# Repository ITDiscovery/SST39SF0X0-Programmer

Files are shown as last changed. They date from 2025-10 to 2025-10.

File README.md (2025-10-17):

# Arduino Mega Parallel Flash Programmer for SST39SF0X0

This project documents a reliable, breadboard-based programmer for SST39SF0X0 series parallel NOR flash chips (SST39SF010, SST39SF020, SST39SF040) using an Arduino Mega 2560. The system was developed to program custom multi-cartridges for the Tandy/Radio Shack Color Computer.

The programmer consists of an Arduino sketch that acts as a hardware interface and a Python script that streams a binary ROM file from a host computer (Mac, PC, or Linux) to the Arduino for programming.

---
## Hardware Required

* **Arduino Mega 2560 R3**: A 5V microcontroller with enough I/O pins to directly drive the flash chip.
* **SST39SF0X0 Series Chip**: e.g., SST39SF020 (256KB) or SST39SF040 (512KB).
* **Breadboard(s)**: Sufficient space for a 32-pin DIP chip and wiring.
* **Jumper Wires**: A good quality set is essential.
* **Two 0.1µF Ceramic Capacitors**: For power decoupling.

  Note: I tried initially to use a AVR128DA64, but timing and jitter created too many issues.

---
## Wiring Diagram

Proper wiring and power integrity are critical for success. Place one 0.1µF capacitor directly across the VCC and GND pins of the Arduino, and the other directly across the VCC and GND pins of the flash chip.

| Signal | SST39SF0X0 Pin | Mega 2560 Pin | Notes |
| :--- | :--- | :--- | :--- |
| **Address** | A0 - A15 | D22 - D37 | 16 contiguous address lines |
| | A16 - A18 | D38 - D40 | Upper 3 address lines |
| **Data** | D0 - D7 | D42 - D49 | Full 8-bit data bus |
| **Control** | #OE (Pin 24) | D50 | Output Enable |
| | #WE (Pin 31) | D51 | Write Enable |
| | #CE (Pin 11) | GND | Chip Enable (tied permanently LOW) |
| **Power** | VCC (Pin 32) | 5V | Connect to 5V rail |
| | GND (Pin 16) | GND | Connect to Ground rail |

---
## How to Use

### Step 1: Build Your Binary ROM File

Use the provided shell scripts to combine your individual 8K or 16K ROM files into a single binary image.

* **For an 8K Multi-Cart (SST39SF020):**
    * Edit the `build_cart.sh` script to list your 8K ROM files.
    * Run the script: `./build_cart.sh`
    * This creates `multicart.bin` (256KB).

* **For a 16K Multi-Cart (SST39SF040):**
    * Edit the `build_16k_cart.sh` script to list your 16K ROM files.
    * Run the script: `./build_16k_cart.sh`
    * This creates `multicart_16k.bin` (512KB).

### Step 2: Prepare the Arduino

1.  Connect your Arduino Mega to your computer.
2.  Open the `SST39SF0X0_Serial_Programmer.ino` sketch in the Arduino IDE.
3.  Upload the sketch to the Mega.
4.  Open the Serial Monitor and confirm it prints "READY".
5.  **Close the Serial Monitor.** This is critical, as the Python script needs exclusive access to the port.

### Step 3: Program the Chip

1.  Make sure Python 3 and the `pyserial` library are installed (`pip3 install pyserial`).
2.  Run the appropriate Python script from your terminal.

* **For the 8K Multi-Cart:**
    ```bash
    python3 upload8k.py
    ```

* **For the 16K Multi-Cart:**
    ```bash
    python3 upload16k.py
    ```
The script will auto-detect the serial port, erase the chip, and then write the binary file, showing you the progress.

---
## Project Files

* `SST39SF0X0_Serial_Programmer.ino`: The firmware for the Arduino Mega. This sketch turns the Arduino into a dedicated hardware programmer that listens for commands over the serial port.
* `upload8k.py`: A Python script for your host computer to program 256KB binary files (e.g., for an SST39SF020).
* `upload16k.py`: A Python script for your host computer to program 512KB binary files (e.g., for an SST39SF040).
* `build_cart.sh`: A shell script template to assemble multiple 8K ROMs into a single 256KB binary image.
* `build_16k_cart.sh`: A shell script template to assemble multiple 16K ROMs into a single 512KB binary image.

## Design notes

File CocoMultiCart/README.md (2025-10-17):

# Dragon64/CoCo Multi-Cartridge

This repository contains the complete hardware design files for a switchable multi-cartridge for the Dragon64/CoCo. The board supports various SST39SF0X0 series flash chips and uses an 8-position DIP switch for bank selection.

---
## Features

* **Chip Support**: Designed for SST39SF010 (128KB), SST39SF020 (256KB), and SST39SF040 (512KB) parallel NOR flash chips in a DIP-32 package.
* **Bank Switching**: An 8-position DIP switch allows for hardware-based bank selection.
* **8K/16K Mode**: A jumper allows for easy switching between 8K and 16K cartridge modes.
* **Custom Case**: Includes an STL file for a 3D-printable cartridge shell.

---
## Repository Contents

* `Gerber_CoCoMultiCart.zip`: Gerber files ready for submission to a PCB manufacturer (like JLCPCB, PCBWay, etc.).
* `CoCoCartridge1.stl`: Contains a matching `.stl` file for the 3D-printable cartridge case.
* `Schem_CoCoMultiCart.pdf`: A document containing the board schematic, layout, and other project details.

---
## How to Build Your Cartridge

### 1. Manufacture the PCB

Upload the `.zip` file from the `/Gerber/` directory to your preferred PCB fabrication service (shout out to JCLPCB).

### 2. Gather Components (Bill of Materials)

| Part | Quantity | Notes |
| :--- | :--- | :--- |
| Custom PCB | 1 | From the Gerber files. |
| SST39SF0X0 Chip | 1 | e.g., SST39SF020 for a 32-in-1 8K cart. |
| 32-pin DIP Socket | 1 | **Highly recommended** to avoid soldering the chip directly. |
| 8-Position DIP Switch | 1 | For bank selection. |
| 10kΩ Resistor Array | 1 | SIP-9 package, for switch pull-ups. |
| 0.1µF Capacitor | 1 | Power supply decoupling. |
| 3-pin Header | 2 | For the 8K/16K mode jumper, autostart jumper.  |
| Jumper Shunt | 2 | To place on the header. |

### 3. Assemble the Board

Solder all components onto the PCB according to the schematic in the PDF. Solder the DIP socket, not the flash chip itself.

### 4. Program the Flash Chip

The flash chip must be programmed **before** it is inserted into the socket on the cartridge.

Use the Arduino Mega Parallel Flash Programmer to build a multi-cart binary image and write it to the chip. Follow the instructions in that repository's README file.

### 5. Print the Case

Print the `.stl` file on your 3D printer to create a protective shell for your finished cartridge.

---
## Usage

1.  Insert the programmed chip into the socket on the cartridge board.
2.  Set the jumper to either **8K** or **16K** mode, depending on the multi-cart binary you created.
3.  Use the DIP switches to select the desired game bank. **Note:** The switches use inverted logic (ON = 0, OFF = 1) due to the pull-up resistors.
4.  Insert the cartridge into your Color Computer and power it on.

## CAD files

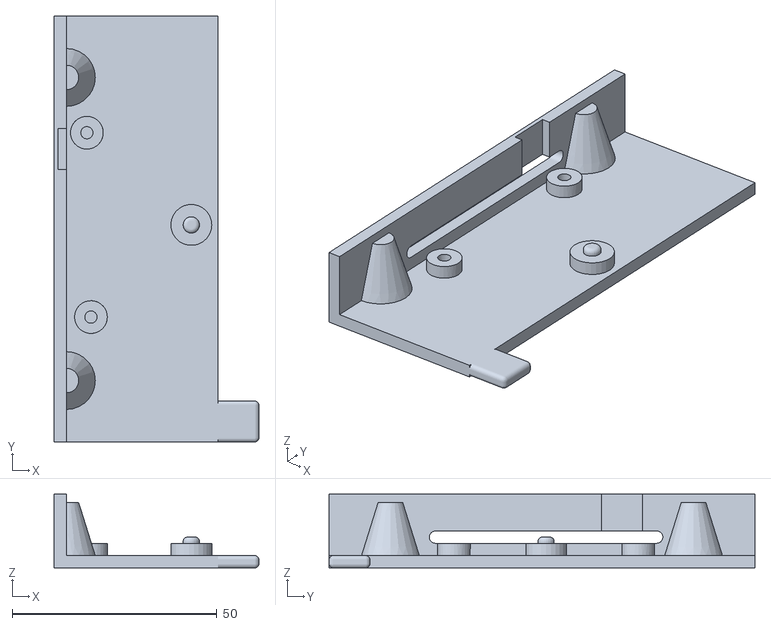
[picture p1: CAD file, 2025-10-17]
CocoMultiCart/CoCoCartridge1.stl
50.0 x 104.0 x 18.0

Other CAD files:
CocoMultiCart/CoCoCartridge.stl

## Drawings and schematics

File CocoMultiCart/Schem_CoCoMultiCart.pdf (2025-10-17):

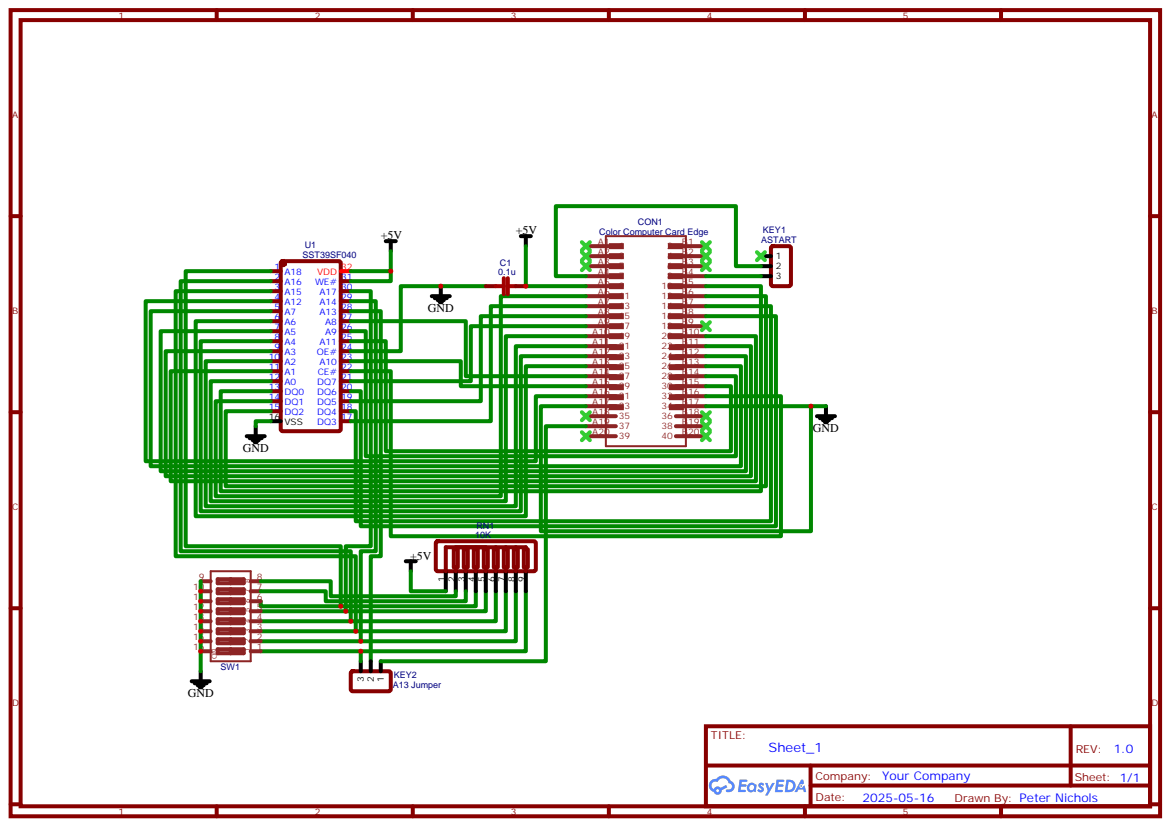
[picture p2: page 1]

Drawn By: Peter Nichols

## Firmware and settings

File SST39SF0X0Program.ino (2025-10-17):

// =============================================================================
// == Pin Definitions for Arduino Mega 2560                                   ==
// =============================================================================
const int OE_PIN = 50;
const int WE_PIN = 51;

// Arrays to hold the pin numbers for easy iteration
const int ADDR_PINS[19] = {22, 23, 24, 25, 26, 27, 28, 29, 30, 31, 32, 33, 34, 35, 36, 37, 38, 39, 40};
const int DATA_PINS[8]  = {42, 43, 44, 45, 46, 47, 48, 49};


// =============================================================================
// == Hardware Abstraction Layer (HAL) for Arduino Mega                       ==
// =============================================================================

// Initializes all the pins used by the programmer.
void hal_init_pins() {
  // Initialize control pins
  pinMode(OE_PIN, OUTPUT);
  pinMode(WE_PIN, OUTPUT);
  digitalWrite(OE_PIN, HIGH); // Inactive
  digitalWrite(WE_PIN, HIGH); // Inactive

  // Initialize address pins
  for (int i = 0; i < 19; i++) {
    pinMode(ADDR_PINS[i], OUTPUT);
  }
  
  // Data bus direction will be set as needed.
}

// Sets the direction of the 8-bit Data Bus
void hal_set_data_bus_direction(bool is_output) {
  for (int i = 0; i < 8; i++) {
    pinMode(DATA_PINS[i], is_output ? OUTPUT : INPUT);
  }
  delayMicroseconds(1); // Small delay for pins to settle
}

// Writes a byte to the Data Bus
void hal_write_data_bus(uint8_t data) {
  for (int i = 0; i < 8; i++) {
    digitalWrite(DATA_PINS[i], (data >> i) & 0x01);
  }
}

// Reads a byte from the Data Bus
uint8_t hal_read_data_bus() {
  uint8_t data = 0;
  for (int i = 0; i < 8; i++) {
    if (digitalRead(DATA_PINS[i]) == HIGH) {
      data |= (1 << i);
    }
  }
  return data;
}

// Sets the 19-bit address on the address bus
void hal_set_address(uint32_t address) {
  for (int i = 0; i < 19; i++) {
    digitalWrite(ADDR_PINS[i], (address >> i) & 0x01);
  }
}

// Pulses the Write Enable (#WE) pin
void hal_pulse_write_enable() {
  digitalWrite(WE_PIN, LOW);
  delayMicroseconds(1); // Meets datasheet minimums
  digitalWrite(WE_PIN, HIGH);
  delayMicroseconds(1); // Recovery time
}

// Controls the Output Enable (#OE) pin
void hal_set_output_enable(bool is_enabled) {
  digitalWrite(OE_PIN, is_enabled ? LOW : HIGH);
}


// =============================================================================
// == High-Level SST39SF0X0 Functions                                         ==
// =============================================================================

// Sends a single command cycle to the flash chip
void sst_send_command(uint32_t address, uint8_t data) {
  hal_set_address(address);
  hal_write_data_bus(data);
  hal_pulse_write_enable();
}

// Reads a single byte from a specified address
uint8_t sst_read_byte(uint32_t address) {
  hal_set_data_bus_direction(false);
  hal_set_address(address);
  hal_set_output_enable(true);
  delayMicroseconds(1); // Give time for output drivers to enable
  uint8_t data = hal_read_data_bus();
  hal_set_output_enable(false);
  return data;
}

// Waits for the chip to finish an operation using Toggle Bit polling.
bool wait_for_completion(uint32_t address) {
  uint8_t read1, read2;
  unsigned long start_time = millis();

  // A real erase can take ~25ms, so a 200ms timeout is safe.
  while (millis() - start_time < 200) {
    read1 = sst_read_byte(address);
    read2 = sst_read_byte(address);
    // Check if DQ6 has stopped toggling
    if ((read1 & 0x40) == (read2 & 0x40)) {
      return true; // Success!
    }
  }
  return false; // Timeout
}

// Erases a 4-KByte sector.
bool sst_sector_erase(uint32_t sector_address) {
  hal_set_data_bus_direction(true);
  
  sst_send_command(0x5555, 0xAA);
  sst_send_command(0x2AAA, 0x55);
  sst_send_command(0x5555, 0x80);
  sst_send_command(0x5555, 0xAA);
  sst_send_command(0x2AAA, 0x55);
  sst_send_command(sector_address, 0x30);
  
  return wait_for_completion(sector_address);
}

// =============================================================================
// == Main Program Logic                                                      ==
// =============================================================================

void setup() {
  Serial.begin(115200);
  hal_init_pins();

  // The Arduino is now ready. It will wait for commands from the Python script.
  Serial.println("READY"); 
}

void loop() {
  // Check if a command has arrived from the computer
  if (Serial.available() > 0) {
    char command = Serial.read();

    if (command == 'E') { // 'E' for Erase
      // Wait for and read the sector number from serial
      while (Serial.available() < 1);
      uint8_t sector_to_erase = Serial.read();
      
      if (sst_sector_erase(sector_to_erase * 4096UL)) {
        Serial.println("OK"); // Acknowledge success
      } else {
        Serial.println("FAIL");
      }
    } 
    else if (command == 'W') { // 'W' for Write
      // Wait for and read the 32-bit address (4 bytes)
      uint32_t address = 0;
      for (int i = 0; i < 4; i++) {
        while (Serial.available() < 1);
        address |= (uint32_t)Serial.read() << (i * 8);
      }

      // Wait for and read the number of bytes to write (2 bytes)
      uint16_t length = 0;
      for (int i = 0; i < 2; i++) {
        while (Serial.available() < 1);
        length |= (uint16_t)Serial.read() << (i * 8);
      }
      
      // Program the bytes one by one as they arrive over serial
      for (uint16_t i = 0; i < length; i++) {
        while (Serial.available() < 1);
        uint8_t data_byte = Serial.read();
        
        hal_set_data_bus_direction(true);
        sst_send_command(0x5555, 0xAA);
        sst_send_command(0x2AAA, 0x55);
        sst_send_command(0x5555, 0xA0);
        sst_send_command(address + i, data_byte);
        
        if (!wait_for_completion(address + i)) {
          Serial.println("FAIL"); // Report failure and stop
          return;
        }
      }
      Serial.println("OK"); // Acknowledge success for the entire block
    }
  }
}

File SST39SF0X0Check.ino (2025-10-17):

#include <avr/io.h>
#include <util/delay.h>

// --- Hardware Abstraction Layer (HAL) based on your wiring ---

// Pin Definitions
#define LED_PIN    7 // PA7
#define OE_PIN     6 // PA6
#define WE_PIN     5 // PA5

// Helper function to initialize all microcontroller pins
void hal_init_pins() {
    // Configure Control Port A (PA5, PA6, PA7) as outputs
    PORTA.DIRSET = (1 << WE_PIN) | (1 << OE_PIN) | (1 << LED_PIN);
    
    // Configure Address Ports C, D, E as outputs
    PORTC.DIR = 0xFF; // A0-A7
    PORTD.DIR = 0xFF; // A8-A15
    PORTE.DIRSET = 0b00000111; // A16-A18
    
    // Set initial states for control lines (HIGH = inactive)
    PORTA.OUTSET = (1 << WE_PIN) | (1 << OE_PIN);
}

// Sets the direction of the 8-bit Data Bus (Port B)
void hal_set_data_bus_direction(bool is_output) {
    if (is_output) {
        PORTB.DIR = 0xFF; // All pins on Port B to Output
    } else {
        PORTB.DIR = 0x00; // All pins on Port B to Input
    }
}

// Writes a byte to the Data Bus (Port B)
void hal_write_data_bus(uint8_t data) {
    PORTB.OUT = data;
}

// Reads a byte from the Data Bus (Port B)
uint8_t hal_read_data_bus() {
    return PORTB.IN;
}

// Sets the 19-bit address on Ports C, D, and E
void hal_set_address(uint32_t address) {
    PORTC.OUT = (uint8_t)(address & 0xFF);         // A0-A7
    PORTD.OUT = (uint8_t)((address >> 8) & 0xFF);  // A8-A15
    
    // A16-A18 on PE0, PE1, PE2
    uint8_t port_e_val = PORTE.OUT & 0b11111000; // Clear lower 3 bits
    if (address & (1UL << 16)) port_e_val |= (1 << 0); // A16 -> PE0
    if (address & (1UL << 17)) port_e_val |= (1 << 1); // A17 -> PE1
    if (address & (1UL << 18)) port_e_val |= (1 << 2); // A18 -> PE2
    PORTE.OUT = port_e_val;
}

// Pulses the Write Enable pin LOW then HIGH with correct timing
void hal_pulse_write_enable() {
    PORTA.OUTCLR = (1 << WE_PIN); // Set #WE LOW
    _delay_us(1);                 // CRITICAL DELAY for Write Pulse Width
    PORTA.OUTSET = (1 << WE_PIN); // Set #WE HIGH
    _delay_us(1);                 // Pause before next operation
}

// Controls the Output Enable pin
void hal_set_output_enable(bool is_enabled) {
    if (is_enabled) {
        PORTA.OUTCLR = (1 << OE_PIN); // Set #OE LOW (Active)
    } else {
        PORTA.OUTSET = (1 << OE_PIN); // Set #OE HIGH (Inactive)
    }
}


// --- High-Level Logic (Now clean and portable) ---

/**
 * @brief Sends a single command cycle to the flash chip.
 * THIS IS THE MODIFIED FUNCTION.
 */
void sst_send_command(uint32_t address, uint8_t data) {
    hal_set_address(address);
    hal_write_data_bus(data);

    // --- NEW DELAY ---
    // This adds an explicit 1 microsecond delay to ensure the address
    // and data lines are perfectly stable before the #WE pulse.
    _delay_us(10000);

    hal_pulse_write_enable();
}

// Reads a byte from a specific address
uint8_t sst_read_byte(uint32_t address) {
    hal_set_address(address);
    hal_set_output_enable(true);
    _delay_us(1); // Give time for output drivers to enable
    uint8_t data = hal_read_data_bus();
    hal_set_output_enable(false);
    return data;
}


// --- Main Application ---

void setup() {
    Serial.begin(115200);
    while (!Serial); // Wait for serial connection
    
    hal_init_pins();
    hal_set_data_bus_direction(true); // Start with bus as output for sending commands

    Serial.println("--- SST39SF020 Programmer Initialized (with setup delay) ---");
    Serial.println("Attempting to read Manufacturer and Device ID...");

    // --- Execute "Software Product ID Entry" Command ---
    sst_send_command(0x5555, 0xAA);
    sst_send_command(0x2AAA, 0x55);
    sst_send_command(0x5555, 0x90);

    // --- Switch to Read Mode ---
    hal_set_data_bus_direction(false); // Bus is now an input

    // --- Read the ID Bytes ---
    uint8_t manufacturer_id = sst_read_byte(0x00000);
    uint8_t device_id = sst_read_byte(0x00001);

    Serial.print("Manufacturer ID: 0x");
    Serial.print(manufacturer_id, HEX);
    Serial.println((manufacturer_id == 0xBF) ? " -> Correct (SST)" : " -> INCORRECT!");

    Serial.print("Device ID: 0x");
    Serial.print(device_id, HEX);
    Serial.println((device_id == 0xB6) ? " -> Correct (SST39SF020)" : " -> INCORRECT!");
    
    // --- Exit ID Mode ---
    hal_set_data_bus_direction(true);
    sst_send_command(0x5555, 0xAA);
    sst_send_command(0x2AAA, 0x55);
    sst_send_command(0x5555, 0xF0);
    hal_set_data_bus_direction(false);
}

void loop() {
    // Test runs once in setup
}
